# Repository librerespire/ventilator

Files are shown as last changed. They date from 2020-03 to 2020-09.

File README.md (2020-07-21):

ventilator

## Overview

An organized group of professionals from multiple disciplines focused on developing an  affordable, medical grade, robust,  open source  solution to acute shortage of mechanical ventilators due to COVID-19 pandemic. We have a core developer group collaborating online from different parts of the world, to design, build, test and validate the prototype.

- Even-though the initiation of the project was due to the COVID-19 outbreak, the LibreRespire team will continue the development of this ventilator to provide this essential medical device at a fraction of the cost of a commercial ventilator to developing countries, which are in dire shortage of ventilators regardless of the COVID-19.

## Objective

To design, build and validate a mechanical ventilator which meets minimum standards for long term ventilation with the aid of 3D printed parts and easily sourced components  which can be customized for local needs.

## Design Philosophy

The design will be publicly available for
- Study
- Modify
- Distribute
- Build
- Sell the design or hardware.

##  Collaborations

Current colloborations include, 

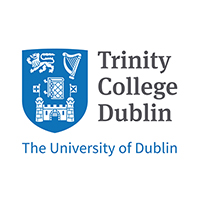
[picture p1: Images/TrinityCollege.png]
ventilator


Mechanical & Manufacturing Engineering, Trinity College, Dublin

If you wish to collaborate and contribute to the project, please contact us via team@librerespire.org. We will respond to every request depending on the requirements.  

## Sections

| Team | Directory |
|---|---|
| Design | [Design](/Design) |
| vBOX_MechanicalConcepts | [vBOX_MechanicalConcepts](/vBOX_MechanicalConcepts) |
| AirDelivery | [AirDelivery](/AirDelivery) |
| Electronics | [Electronics](/Electronics) |
| PowerSupply | [PowerSupply](/PowerSupply) |
| Housing | [Housing](/Housing) |

## Team
The core team consists of, 
- Manjula Herath (BDS,MD)
- Anuradha Rajapaksha (MBBS, MD,MRCS)
- Nushen Senevirathna (BSc Eng, MSc Eng) 
- Chamath Divarathne (Bsc Eng, MSc Eng, PhD)
- Roshana Mallawaarachchi (MBBS,MD)
- Nipuna Perera (Bsc)
- Chamila Dissanayake (Bsc Eng, MSc Eng)
- Rajive Wisidagama (BSc Eng, MSc Eng)
- Evaggelia Papia (PhD, DT),
- Prasad Ranaraja (Bsc Eng,Pg Dip, MBA)
- Sahan Wasala (ME (Aerospace), PhD) 
- Sameera Nanayakkara (BSc Eng, MSc Eng)

## Disclaimer

Currently LibreRespire ventilator is at experimental stage and not been validated  and approved for human or animal use clinically.

THE VENTILATOR INFORMATION IS PROVIDED “AS-IS, WHERE-IS,” WITHOUT REPRESENTATIONS, CONDITIONS, OR WARRANTIES OF ANY KIND, WHETHER EXPRESS OR IMPLIED, INCLUDING, BUT NOT LIMITED TO,  WARRANTIES OF MERCHANTABILITY OR FITNESS FOR A PARTICULAR PURPOSE, OR THAT THE USE OF THE VENTILATOR INFORMATION WILL NOT INFRINGE ANY PATENT, COPYRIGHT, TRADEMARK, OR OTHER PROPRIETARY RIGHTS.   THE RECIPIENT IS SOLELY RESPONSIBLE FOR DETERMINING THE APPROPRIATENESS OF USING, REPLICATING, OR REDISTRIBUTING THE LIBRERESPIRE VENTILATOR PROJECT INFORMATION AND DESIGN. IN THIS REGARD, THE RECIPIENT ASSUMES ALL LIABILITY FOR DAMAGES, OF WHATEVER NATURE AND DESCRIPTION, WHETHER IN CONTRACT OR IN TORT, WHICH MAY ARISE FROM THE USE OF THE VENTILATOR INFORMATION AND DESIGN.  THE LIBRERESPIRE TEAM, WILL NOT BE LIABLE TO THE RECIPIENT OR TO ANY THIRD PARTY FOR ANY LOSS, CLAIM, OR DEMAND MADE BY THE RECIPIENT, OR ANY LOSS, CLAIM, DEMAND, OR JUDGMENT AGAINST THE RECIPIENT BY ANY OTHER PARTY, DUE TO OR ARISING FROM THE USE OF THE VENTILATOR INFORMATION AND DESIGN BY THE RECIPIENT.

## Repository

Design documents can find [here](https://github.com/librerespire/ventilator)

## Team contacts

- Team email: [team@librerespire.org](mailto:team@librerespire.org)
- Slack channel: [librerespireorg.slack.com](https://librerespireorg.slack.com)

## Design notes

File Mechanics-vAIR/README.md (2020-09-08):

## Overview

This LibreRespire ventilator is organized in to two main components. This section
mainly focused on the vAIR.

- vBOX
  - The ventilator box which houses the main controllers and can functions
    independent of the gas delivery system, vAIR.

- vAIR
  - The ventilator air delivery system is responsible for the delivery of medical
    air and oxygen to the vBOX.

The main emphasis and development effort is focused on the vBOX. The goal is to
develop the vBOX to be couple with any standard gas delivery system such as wall
air, cylinders, compressors. bellows and pistons.

## Objective

However this section focuses on development of vAIR, the LibreRespire gas air delivery
system  which currently designed to work with the wall oxygen
and wall medical air. We
intend to build efficient, cost effective and easily sourced driving mechanism for
the vBOX.

## Team contacts

- Team email: [team@librerespire.org](mailto:team@librerespire.org)
- Slack channel: [librerespireorg.slack.com](https://librerespireorg.slack.com)

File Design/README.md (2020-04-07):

## The design

The design of the ventilator is based on the minimum standards published by the British government [here](https://www.gov.uk/government/publications/coronavirus-covid-19-ventilator-supply-specification/rapidly-manufactured-ventilator-system-specification)

## Objectives

- Design a ventilator composed of mechanical components freely available in most
regions of the world.
- Design a ventilator without the use of a Bellow or a “Bag”, which is either not
available or limited in number in an emergency situation.
- Minimize the use of mechanically moving components to increase durability.
- Easily sourced and easily assembled by a technician with limited medical
knowledge with off-the-shelf components.
- Option to use “Wall” oxygen / oxygen cylinders or a combination.
- Retain the capability to tolerate significant pressure difference or fluctuations.
- Be effective while retaining all the safety features.
- Maintain total cost of manufacture of the ventilator within affordable range,
especially to support developing countries.
- Use a programmable chip as a microcontroller which is a cheaper option yet be
powerful enough for real-time calculations.
- Use a visual aid (LCD) which is informative as well as user friendly.
- Ensuring a safe, reliable and robust design on par with industry standards.

## Functional specification

- Functional Modes
a. Pressure control Continuous Mandatory Ventilation (PC- CMV)
b. Pressure control Intermittent Mandatory Ventilation (PC-IMV)
c. Continuous Positive Air Pressure (CPAP)

- Gas supply
a. Air and O2 supplied separately
b. Option to use wall connectors (4Bar) or Cylinder(Variable Pressure) - System can
compensate for pressure drop/variation

- Visual controls and digital features
a. Feedback control of pressure and flow.
b. Ventilator output for TV, RR, PEEP, PIP, MV, Spontaneous ventilation rate
c. Alarms
d. iOS and Android controller app with a dashboard to display patient data for
remote monitoring
e. Data analytic as an added feature for pattern recognition etc. for assisting
doctors

## Hardware specification

| Parameter | Range | Accuracy | Adjustments |
|---|---|---|---|
| Tidal volume (TV) | 250-1000 ml |  25 ml |  10 ml |
| Respiratory rate (RR)) | 10 – 30 bpm | 0.5 bpm | 1 bpm |
| I:E ratio | 1:3 - 2:1 | |  0.1 |
| Oxygen saturation | FiO2 0.21 - 1.0 | 0.05 |  |
| FiO<sub>2</sub> | 0.21 - 1.0 |  5% |  10% |
| Peak inspiratory pressure | 40 mmHg |  1 mmHg |  1 mmHg |
| Safety valve | 40 - 60 mmHg |  Absolute |  +5 mmHg |
| Inspiratory pause | 25% | |  1% |

## Main control unit

- Processing
  - 32 bit ARM
- Display
  - LCD, 5", capacitive touchscreen (option to use a low cost 3” to high end10” designs)
- Alarms
  - Low RR
  - Low TV
  - PIP
  - Circuit leaks/disconnections
  - Circuit obstruction

## Sensors

- Pressure sensors
- Oxygen sensor
- Flow sensor

## Valve Specifications

- Actuated pneumatic solenoid valve NC
- Needle valve
- Solenoid Valve NO
- Safety valves
- One way rubber diaphragm valves
- PEEP Valve

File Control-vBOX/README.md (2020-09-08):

## Overview

The LibreRespire ventilator is organized in to two main components. This section
mainly focused on the vBOX, the heart of the LibreRespire system.

- vBOX
  - The ventilator box which houses the main controllers and sensors and can functions independent of the gas delivery system, vAIR.

- vAIR
  - The ventilator air delivery system is responsible for the delivery of medical
    air and oxygen to the vBOX.

The main emphasis and development effort is focused on the vBOX. The goal is to
develop the vBOX to be couple with any standard gas delivery system such as wall
air, cylinders, compressors. bellows and pistons.

## Objective

The main driving concept behind the LibreRespire development is its modular design
which can be tailored to the individual needs and can easily experimented, debugged
and improved.

## Design

The vBOX is divided in to 6 modules.
- iMixingUnit
  - Responsible for medical air and oxygen mixing to maintain a given FiO<sub>2</sub>.
    Currently  FiO<sub>2</sub> needs to be set manually.
    - Issue tracker.
       * [ ]  Automate  FiO<sub>2</sub> setting.
       * [ ]  Select appropriate oxygen sensor.
       * [ ]  Integrate oxygen sensor.
       * [ ]  Improve physical design.   

- iVenturiUnit
  - Responsible for sensing the pressure difference and flow rates in the control
  loop during inspiration. Operates on bernoulli's principle and allows the flow
  rate to be calculated independent of a separate flow sensor.
  - Issue tracker.
     * [ ]  Selection of a single differential pressure sensor.
     * [ ]  Improve physical design.

- iControlUnit
  - The main inspiratory output. Houses the emergency valve and the one way valve.  
  - Issue tracker.
     * [ ]  Select appropriate rupture disk to act as the emergency valve.
     * [ ]  Decide on the cost effectiveness of a separate flow sensor.
     * [ ]  Optimize one way valve.
     * [ ]  Standardize output port.

- eControlUnit
  - The main port of entry of the expiratory limb. Houses one way valve and the
  main flow sensor.
  Issue tracker.
    * [ ]  Select appropriate flow sensor.

- eVenturiUnit
  - Act to control the expiratory flow and calculate the pressure difference and the
  expiratory flow rates.
  - Issue tracker.
     * [ ]  Selection of a single differential pressure sensor.

- ePEEPControl
  - Currently controlled by the off the shelf manual PEEP valve.
  - Issue tracker.
     * [ ]  Development of a electronically controlled PEEP valve.
     * [ ]  Validation of the electronically controlled PEEP valve.

## Team contacts

- Team email: [team@librerespire.org](mailto:team@librerespire.org)
- Slack channel: [librerespireorg.slack.com](https://librerespireorg.slack.com)

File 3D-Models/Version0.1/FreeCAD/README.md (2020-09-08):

This folder contains CAD drawings in FreeCAD format

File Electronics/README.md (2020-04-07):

ventilator

# LibreRespire Electronic module
---

This functions as the brain of the LibreRespire, and tailors the output to the
user specified settings based on sensory input.   

## Repository

Design documents can find [here](https://github.com/librerespire/ventilator)

## Team contacts

- Team email: [team@librerespire.org](mailto:team@librerespire.org)
- Slack channel: [librerespireorg.slack.com](https://librerespireorg.slack.com)

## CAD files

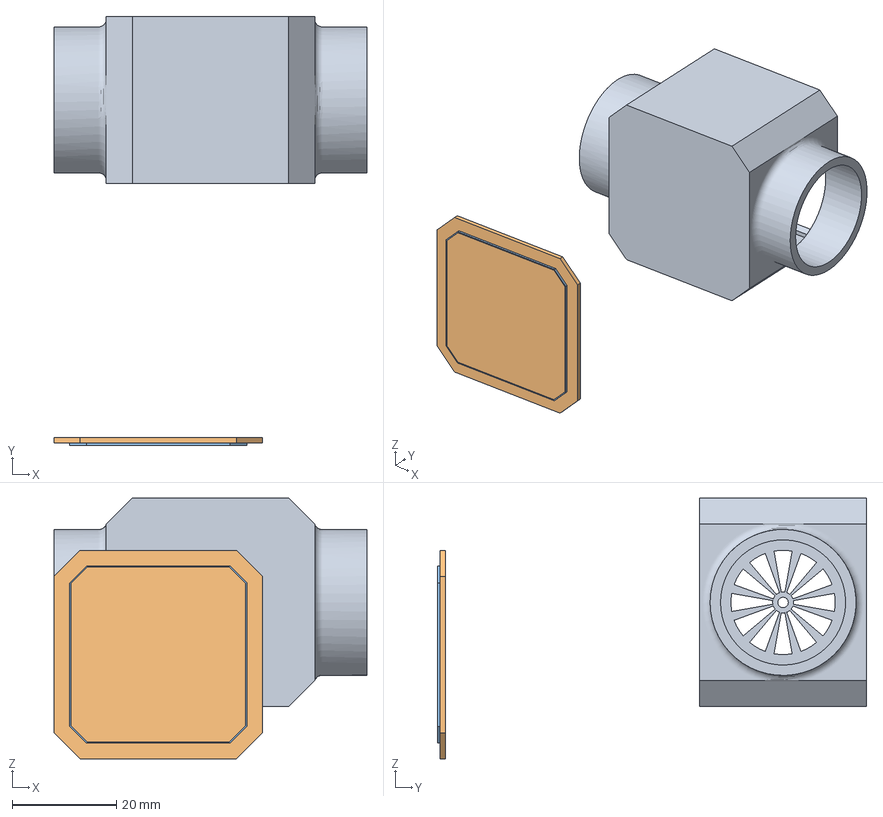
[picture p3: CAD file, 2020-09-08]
3D-Models/Version0.1/FreeCAD/ExpirationChamber.FCStd
60.0 x 82.3 x 50.0 mm
ExpirationChamber-CAP

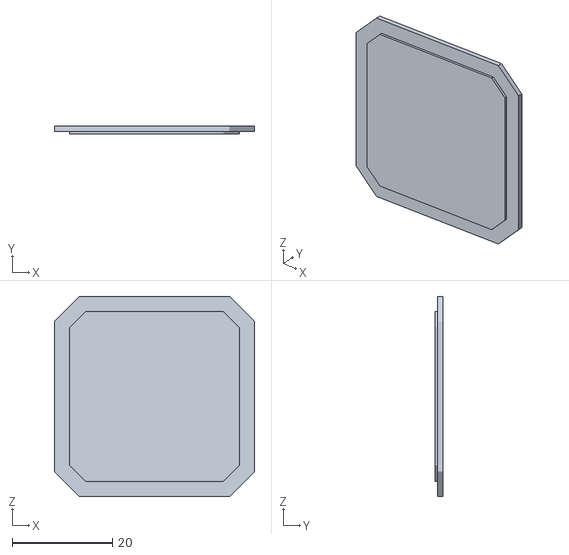
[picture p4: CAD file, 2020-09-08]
3D-Models/Version0.1/InspiControlChamberCap.STL
40.0 x 1.50 x 40.0

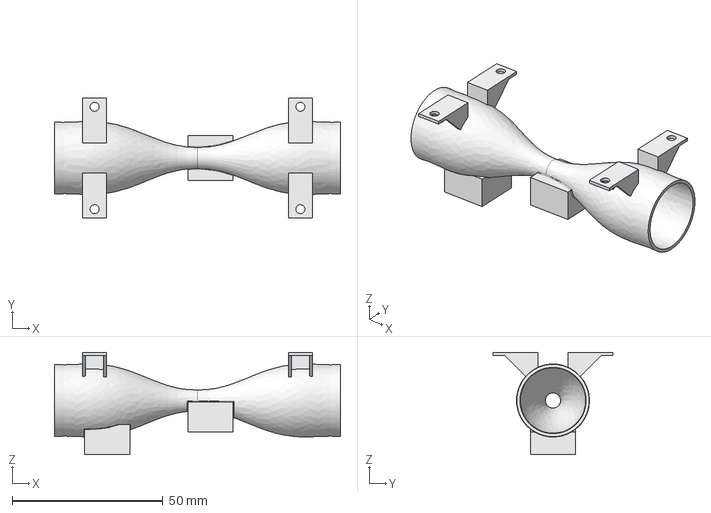
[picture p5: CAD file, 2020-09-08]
3D-Models/Version0.1/FreeCAD/VentureTube.FCStd
95.0 x 40.0 x 34.0 mm

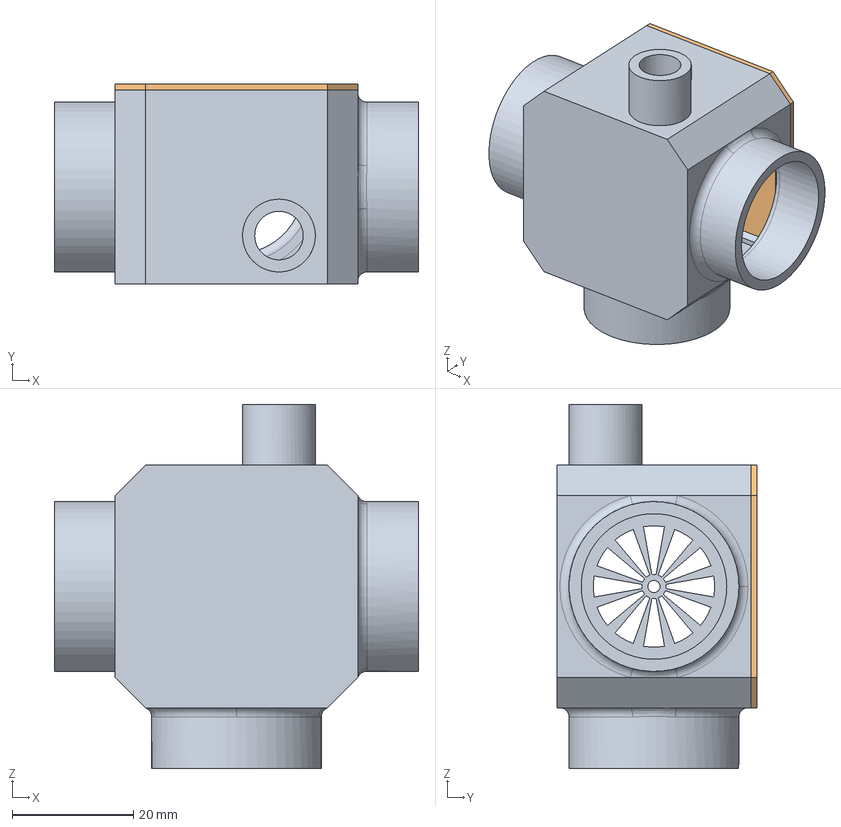
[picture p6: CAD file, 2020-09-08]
3D-Models/Version0.1/FreeCAD/InspiControlChamber.FCStd
60.0 x 33.0 x 60.0 mm

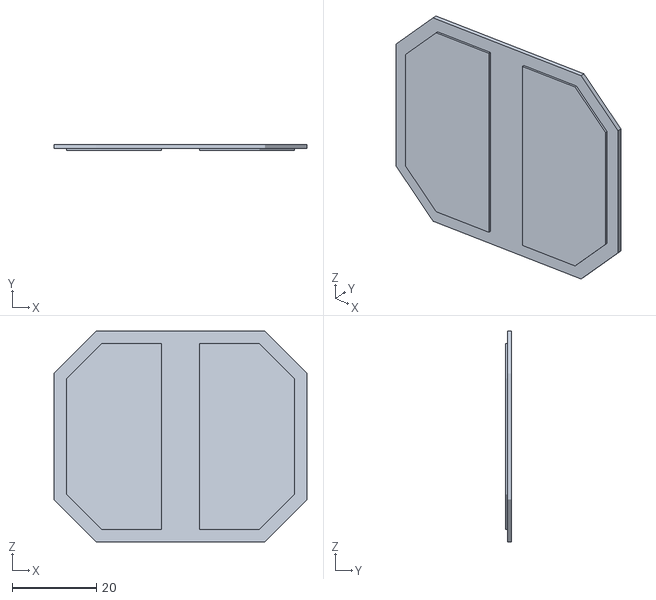
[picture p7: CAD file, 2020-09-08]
3D-Models/Version0.1/MixingChamberCap.STL
60.0 x 1.50 x 50.0

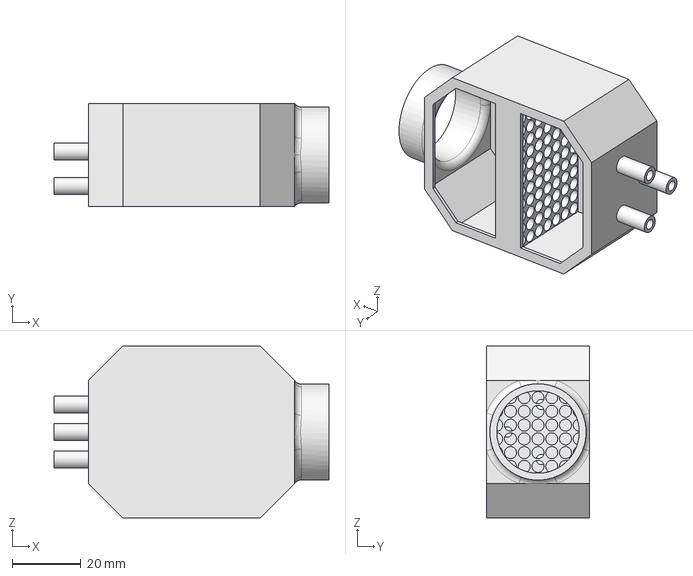
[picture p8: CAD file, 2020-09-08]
3D-Models/Version0.1/FreeCAD/MixingChamber.FCStd
80.0 x 30.0 x 50.0 mm

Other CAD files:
3D-Models/Version0.1/ExpirationChamber-CAP.stl
3D-Models/Version0.1/VenturiTube.STL
3D-Models/Version0.1/ExpirationChamber.stl
3D-Models/Version0.1/InspiControlChamber.STL
3D-Models/Version0.1/MixingChamber.STL

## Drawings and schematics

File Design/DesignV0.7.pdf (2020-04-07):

## Air Delivery Unit

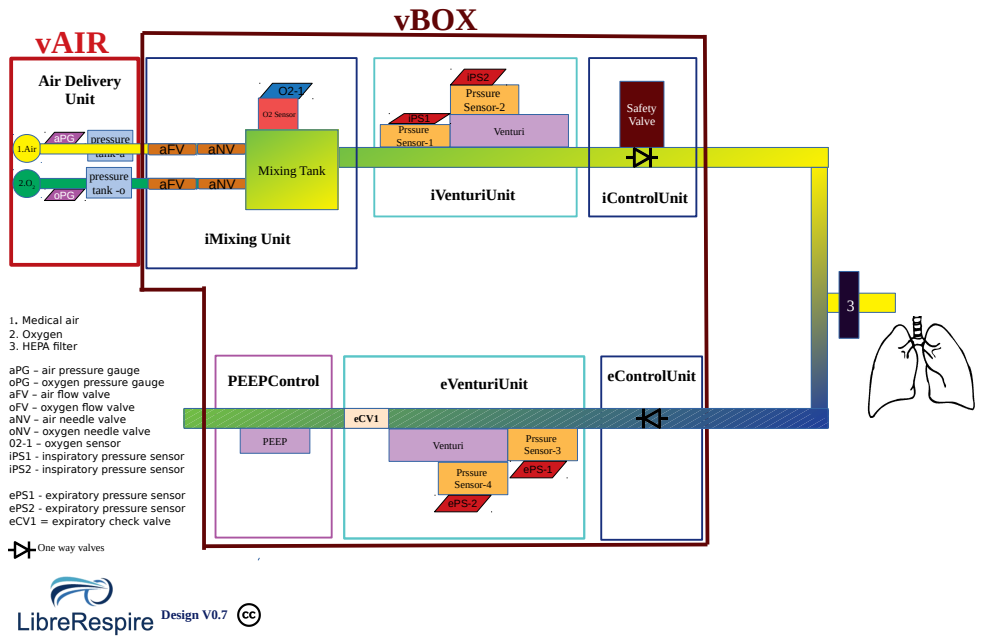
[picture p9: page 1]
1. Medical air 2. Oxygen 3. HEPA filter; Design V0.7; pressure tank-a ¹.Air; aPG; iControlUnit; Safety Valve; oPG; iVenturiUnit; Venturi; Prssure Sensor-2; iPS2; Prssure Sensor-1; iPS1; aNV; pressure; tank -o; aFV; Prssure; ePS-1; Sensor-4; ePS-2; iMixing Unit; vBOX; eVenturiUnit; eControlUnit; O2 Sensor; PEEPControl; Mixing Tank; vAIR

aPG – air pressure gauge
oPG – oxygen pressure gauge
aFV – air flow valve
oFV – oxygen flow valve
aNV – air needle valve
oNV – oxygen needle valve
02-1 – oxygen sensor
iPS1 - inspiratory pressure sensor
iPS2 - inspiratory pressure sensor

eCV1

PEEP | | Venturi | Prssure Sensor-3

ePS1 - expiratory pressure sensor
ePS2 - expiratory pressure sensor
eCV1 = expiratory check valve

One way valves

Design V0.7

## Power Supply

## Plugged in

## Rechargeable/Hot swappable

## MCU

## User Interface

I:E Ratio

2:1 – 1:2

Respiratory Rate
5-40 bpm

Expiratory pressure I:E Ratio 0 - 20 cmH20

## FiO2

20% -100% | Active Buzzer Alarm Inspiratory pressure
40 cmH20

Minute Ventilation (low/High) alarm Peak pressure, Low expiratory pressure Disconnection alarm
Low expiratory pressure
Oxygen concentration
Non-rebreathing valves

## Pressure Support

5-15

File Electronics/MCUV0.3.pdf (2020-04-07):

uIP | uRR | uPEEP | uPS | uTV
Pressure | Flow | O2

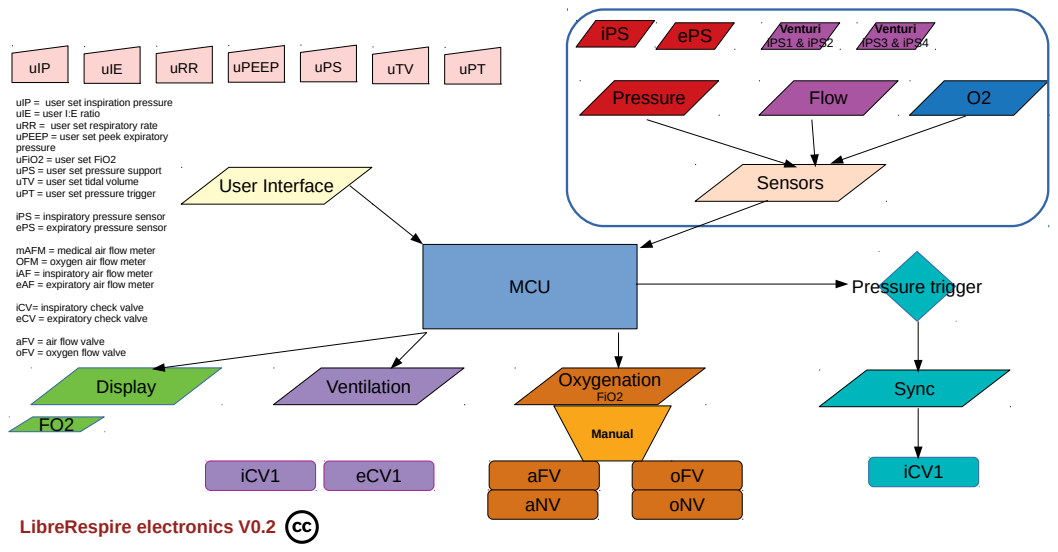
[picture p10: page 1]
MCU; Sensors; Display; Ventilation; Oxygenation; FiO2; Sync; User Interface; iPS; ePS; Venturi; iPS1 & iPS2; Venturi iPS3 & iPS4; iCV1; eCV1; aFV; oFV; Pressure trigger; LibreRespire electronics V0.2; uIE; uPT; aNV; oNV; Manual FO2

uIP = user set inspiration pressure
uIE = user I:E ratio
uRR = user set respiratory rate
uPEEP = user set peek expiratory
pressure
uFiO2 = user set FiO2
uPS = user set pressure support
uTV = user set tidal volume
uPT = user set pressure trigger

iPS = inspiratory pressure sensor
ePS = expiratory pressure sensor

mAFM = medical air flow meter
OFM = oxygen air flow meter
iAF = inspiratory air flow meter
eAF = expiratory air flow meter

iCV= inspiratory check valve
eCV = expiratory check valve

aFV = air flow valve
oFV = oxygen flow valve

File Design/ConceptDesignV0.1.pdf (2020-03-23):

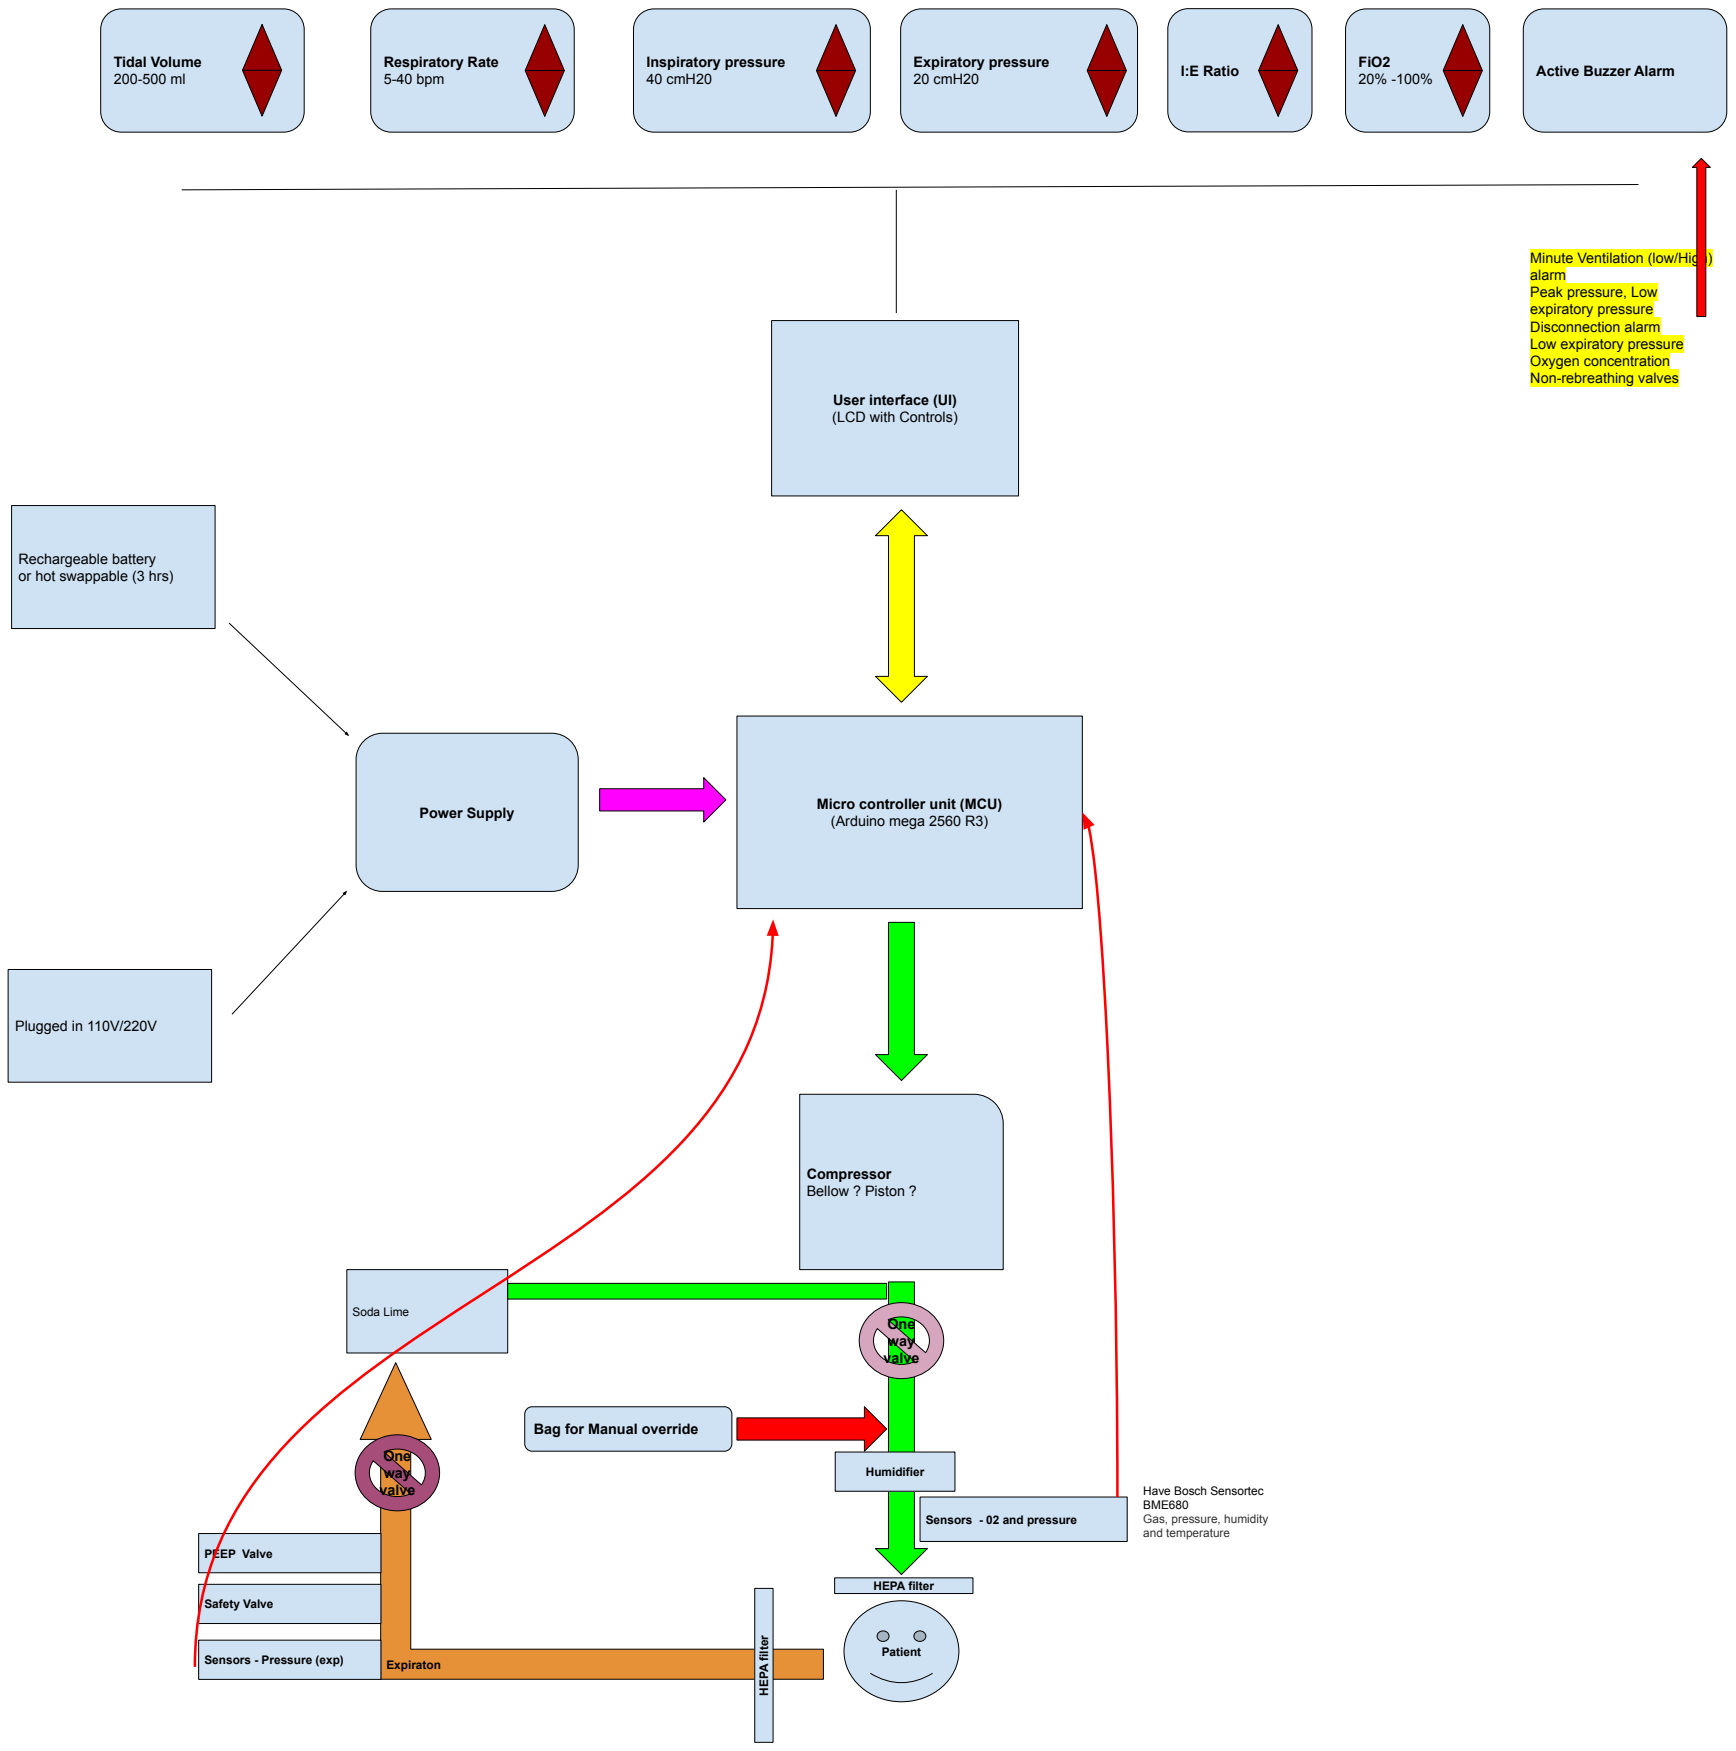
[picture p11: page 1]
Power Supply; Plugged in 110V/220V; Tidal Volume 200-500 ml; Respiratory Rate 5-40 bpm; Inspiratory pressure 40 cmH20; Expiratory pressure 20 cmH20; I:E Ratio; Active Buzzer Alarm; FiO2 20% -100%; Compressor Bellow ? Piston ?; One way valve; Humidifier; Patient; Soda Lime; Expiraton; Safety Valve; HEPA filter; PEEP Valve

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

User interface (UI)
(LCD with Controls)

Rechargeable battery
or hot swappable (3 hrs)

Micro controller unit (MCU)
(Arduino mega 2560 R3)

Bag for Manual override

Have Bosch Sensortec
BME680
Gas, pressure, humidity
and temperature

Sensors - 02 and pressure

Sensors - Pressure (exp)

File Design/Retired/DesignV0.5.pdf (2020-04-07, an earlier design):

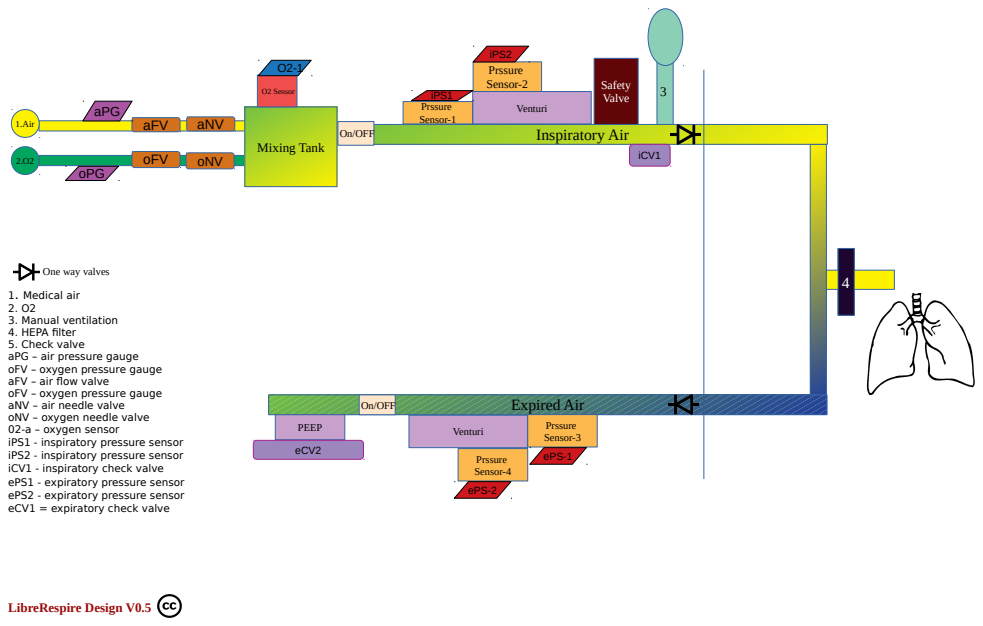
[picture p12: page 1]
Inspiratory Air; LibreRespire Design V0.5; Safety Valve; Mixing Tank; iCV1; eCV2; aFV; oFV; O2 Sensor; aPG; oPG; oNV; aNV; Prssure; ePS-1; Sensor-4; ePS-2; Venturi; Prssure Sensor-2; iPS2; Prssure Sensor-1; iPS1; 1.Air; On/OFF

One way valves
1. Medical air
3. Manual ventilation
4. HEPA filter
5. Check valve
aPG – air pressure gauge
oFV – oxygen pressure gauge
aFV – air flow valve
aNV – air needle valve
oNV – oxygen needle valve
02-a – oxygen sensor
iPS1 - inspiratory pressure sensor
iPS2 - inspiratory pressure sensor
iCV1 - inspiratory check valve
ePS1 - expiratory pressure sensor
ePS2 - expiratory pressure sensor
eCV1 = expiratory check valve

On/OFF | Expired Air

PEEP | | Venturi | Prssure Sensor-3

LibreRespire Design V0.5

## Power Supply

## Plugged in

## Recharhable/Hot swappable

## MCU

(Arduino mega 2560 R3)

## User Interface

I:E Ratio

2:1 – 1:2

Respiratory Rate
5-40 bpm

Expiratory pressure I:E Ratio 0 - 20 cmH20

## FiO2

20% -100% | Active Buzzer Alarm Inspiratory pressure
40 cmH20

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

## Pressure Support

5-15

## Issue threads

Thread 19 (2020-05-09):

Mechanical vs electronic PEEP

cmfsx, 2020-05-09:
P3 PEEP is not relevant if the PEEP valve is mechanical. P3 PEEP should be included in the loop when electronically controlled PEEP valve is used.

https://github.com/librerespire/ventilator/blob/519f6ead6bdfed8257125dfd74dad3634d3425b2/Firmware/RaspberryPi/backend-pi/Controller.py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

chamrepo, 2020-05-17:
Controlling pressure was made out of scope for this mode

Closed 2020-05-17.

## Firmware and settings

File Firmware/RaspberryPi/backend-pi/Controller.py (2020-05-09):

# Controller v1.1
# 2020-05-09 12.05 AM (Melb)

import math
import time
from datetime import datetime
import threading
import RPi.GPIO as GPIO
from SensorReader import SensorReader
import logging.config

# Parameters
Ti = 5          # inspiratory time
Te = 5          # expiratory time
Tw = 1          # waiting time
Vt = 5          # tidal volume
Pi = 2000       # peak inspiratory pressure in cmH2O
Peep = 900      # PEEP
PWM_FREQ = 4    # frequency for PWM

# Constants
SI_PIN = 12     # PIN (PWM) for inspiratory solenoid
SE_PIN = 13     # PIN (PWM) for expiratory solenoid
DUTY_RATIO_100 = 100
DUTY_RATIO_0 = 0
NUMBER_OF_SENSORS = 4
BUS_1 = 1
BUS_2 = 3
BUS_3 = 4
BUS_4 = 5

pressure_data = [0] * 6

# Initialize digital output pins
GPIO.setmode(GPIO.BCM)
GPIO.setwarnings(False)

GPIO.setup(SI_PIN, GPIO.OUT)
GPIO.setup(SE_PIN, GPIO.OUT)

pwm_i = GPIO.PWM(SI_PIN, PWM_FREQ)
pwm_e = GPIO.PWM(SE_PIN, PWM_FREQ)

# declare logger parameters
logging.config.fileConfig(fname='logger.conf', disable_existing_loggers=False)
logger = logging.getLogger(__name__)


def thread_slice(pressure_data, index):
    sr = SensorReader(index)
    pressure = sr.read_pressure()
    pressure_data[index] = pressure


def read_data():
    # read four pressure sensors from the smbus and return actual values
    threads = list()
    for index in [BUS_1, BUS_2, BUS_3, BUS_4]:
        thread = threading.Thread(target=thread_slice, args=(pressure_data, index,))
        threads.append(thread)
        thread.start()

    for index, thread in enumerate(threads):
        thread.join()
    logger.debug("Pressure: P1[%.2f], P2[%.2f], P3[%.2f], P4[%.2f]" %
                 (pressure_data[BUS_1], pressure_data[BUS_2], pressure_data[BUS_3], pressure_data[BUS_4]))
    return pressure_data[BUS_1], pressure_data[BUS_2], pressure_data[BUS_3], pressure_data[BUS_4]


def calculate_k(p1, p2, flow_rate):
    return flow_rate / math.sqrt(abs(p1 - p2))


# With current settings flow meter will be calibrated over 5 seconds (nSamples * delay)
def calibrate_flow_meter(flow_rate):
    """ returns the calibrated k for both insp and exp flow meters, calculated based on multiple pressure readings """

    # Turn ON both the solenoids fully for calibration
    pwm_i.start(100)
    pwm_e.start(100)

    nSamples = 10  # average over 10 samples
    delay = 0.5  # 0.5 seconds
    n = 0
    ki = 0
    ke = 0
    # Take the average over 'nSamples' pressure readings, 'delay' seconds apart to calculate k
    while n < nSamples:
        p1, p2, p3, p4 = read_data()
        ki += calculate_k(p1, p2, flow_rate)
        ke += calculate_k(p3, p4, flow_rate)
        n += 1
        time.sleep(delay)

    ki /= nSamples
    ke /= nSamples
    logger.debug("Flow meter was calibrated. k_ins = %.4f, k_exp = %.4f" % (ki, ke))
    return ki, ke


def control_solenoid(pin, duty_ratio):
    if pin == SI_PIN:
        pwm_i.ChangeDutyCycle(duty_ratio)
    elif pin == SE_PIN:
        pwm_e.ChangeDutyCycle(duty_ratio)

    logger.debug("Changed duty cycle to " + str(duty_ratio) + "on pin " + str(pin))

# def control_solenoid(pin, duty_ratio):
#     # read four pressure sensors from the smbus and return actual values
#     logger.info("Entering control_solenoid()...")
#     on_time = PWM_PERIOD * duty_ratio
#     off_time = PWM_PERIOD * (1 - duty_ratio)
#
#     if pin in threads_map:
#         threads_map[pin].stop()
#         threads_map[pin].join()
#
#     t = PWMController(datetime.now().strftime('%Y%m%d%H%M%S%f'), pin, on_time, off_time)
#     threads_map[pin] = t
#
#     # Don't want these threads to run when the main program is terminated
#     t.daemon = True
#     t.start()
#
#     logger.info("Leaving control_solenoid().")


def get_average_volume_rate(is_insp_phase):
    """ read p1 and p2 over 200 milliseconds and return average volume rate """

    nSamples = 4  # average over 4 samples
    delay = 0.05  # 50 milliseconds
    n = 0
    q = 0
    # Take the average over 'nSamples' pressure readings, 'delay' seconds apart to calculate flow rate
    while n < nSamples:
        p1, p2, p3, p4 = read_data()
        if is_insp_phase:
            q += Ki * math.sqrt(abs(p1 - p2))
        else:
            q += Ke * math.sqrt(abs(p3 - p4))

        n += 1
        time.sleep(delay)

    return q / nSamples


def calculate_pid_duty_ratio(demo_level):
    """ TODO: implement the PID controller to determine the required duty ratio to achieve the desired pressure curve
        Currently a temporary hack is implemented with demo_level """
    duty_ratio = 100
    if demo_level == 1:
        duty_ratio = 20

    return duty_ratio


def insp_phase(demo_level):
    """ inspiratory phase tasks
        demo_level is a temporary hack to introduce two flow rate levels until pid controller is implemented """

    logger.info("Entering inspiratory phase...")
    start_time = datetime.now()
    t1, t2 = start_time, start_time
    ti = 0
    q1, q2 = 0, 0
    vi = 0

    # Control solenoids
    control_solenoid(SE_PIN, DUTY_RATIO_0)

    while ti < Ti and vi < Vt:
        t1 = t2
        q1 = q2
        q2 = get_average_volume_rate(True)
        t2 = datetime.now()

        vi += (q1 + q2) / 2 * (t2 - t1).total_seconds() / 60

        di = calculate_pid_duty_ratio(demo_level)
        control_solenoid(SI_PIN, di)

        ti = (datetime.now() - start_time).total_seconds()
        logger.info("Flow rate: %.2f L/min, Volume: %.2f L,  Time: %.1f sec" % (q2, vi, ti))

    logger.info("Leaving inspiratory phase.")


def exp_phase():
    """ expiratory phase tasks """
    logger.info("Entering expiratory phase...")
    start_time = datetime.now()
    t1, t2 = start_time, start_time
    ti = 0
    q1, q2 = 0, 0
    vi = 0
    p3 = Peep

    control_solenoid(SI_PIN, DUTY_RATIO_0)
    control_solenoid(SE_PIN, DUTY_RATIO_100)

    while ti < Te and p3 >= Peep:
        t1 = t2
        q1 = q2
        q2 = get_average_volume_rate(False)
        t2 = datetime.now()

        vi += (q1 + q2) / 2 * (t2 - t1).total_seconds() / 60

        p1, p2, p3, p4 = read_data()
        if p3 < Peep:
            control_solenoid(SE_PIN, 0)

        ti = (datetime.now() - start_time).total_seconds()
        logger.info("Flow rate: %.2f L/min, Volume: %.2f L, Pressure_insp: %.2f cmH20, Time: %.1f sec"
                    % (q2, vi, convert_pressure(p3), ti))

    logger.info("Leaving expiratory phase.")
    logger.info("Actual tidal volume delivered : %.3f L " % vi)


def wait_phase():
    """ waiting phase tasks """
    logger.info("Entering wait phase...")
    control_solenoid(SI_PIN, DUTY_RATIO_0)
    control_solenoid(SE_PIN, DUTY_RATIO_0)
    time.sleep(Tw)
    logger.info("Leaving wait phase.")


def convert_pressure(p_hpa):
    """ returns inspiratory pressure in cmH2O"""
    return p_hpa * 1.0197442


#######################################################################################################
# 12 here is the intended flow_rate for calibration in L/min
Ki, Ke = calibrate_flow_meter(12)

while True:
    # slow flow rate
    # logger.info("***** Slower flow rate cycle *****")
    # insp_phase(1)
    # exp_phase()
    # wait_phase()
    # logger.info("***** Slower cycle end *****")

    # faster flow rate
    logger.info("***** Faster flow rate cycle *****")
    insp_phase(2)
    exp_phase()
    wait_phase()
    logger.info("***** Faster cycle end *****")

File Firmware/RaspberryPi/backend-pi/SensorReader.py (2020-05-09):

import smbus
import time
from datetime import datetime


class SensorReader:
    bus = None
    delay = 0.05
    pressure = -0
    cTemp = 999
    fTemp = 999
    bus_number = 0

    def __init__(self, bus_number):
        # Get I2C
        self.bus_number = bus_number
        self.bus = smbus.SMBus(self.bus_number)

    def read_temp(self):
        #Reading Data from i2c bus 3
        b1 = self.bus.read_i2c_block_data(0x76, 0x88, 24)
        # Convert the data
        # Temp coefficents
        dig_T1 = b1[1] * 256 + b1[0]
        dig_T2 = b1[3] * 256 + b1[2]
        if dig_T2 > 32767 :
            dig_T2 -= 65536
        dig_T3 = b1[5] * 256 + b1[4]
        if dig_T3 > 32767 :
            dig_T3 -= 65536
        # BMP280 address, 0x76(118)
        # Select Control measurement register, 0xF4(244)
        #		0x27(39)	Pressure and Temperature Oversampling rate = 1
        #					Normal mode
        self.bus.write_byte_data(0x76, 0xF4, 0x27)
        # BMP280 address, 0x76(118)
        # Select Configuration register, 0xF5(245)
        #		0xA0(00)	Stand_by time = 1000 ms
        self.bus.write_byte_data(0x76, 0xF5, 0xA0)
        time.sleep(self.delay)
        # BMP280 address, 0x76(118)
        # Read data back from 0xF7(247), 8 bytes
        # Pressure MSB, Pressure LSB, Pressure xLSB, Temperature MSB, Temperature LSB
        # Temperature xLSB, Humidity MSB, Humidity LSB
        data = self.bus.read_i2c_block_data(0x76, 0xF7, 8)
        # Convert temperature data to 19-bits
        adc_t = ((data[3] * 65536) + (data[4] * 256) + (data[5] & 0xF0)) / 16
        # Temperature offset calculations
        var1 = ((adc_t) / 16384.0 - (dig_T1) / 1024.0) * (dig_T2)
        var2 = (((adc_t) / 131072.0 - (dig_T1) / 8192.0) * ((adc_t)/131072.0 - (dig_T1)/8192.0)) * (dig_T3)
        t_fine = (var1 + var2)
        self.cTemp = (var1 + var2) / 5120.0
        self.fTemp = self.cTemp * 1.8 + 32

    def read_pressure(self):
        #Reading Data from i2c bus 3
        b1 = self.bus.read_i2c_block_data(0x76, 0x88, 24)
        # Convert the data
        # Temp coefficents
        dig_T1 = b1[1] * 256 + b1[0]
        dig_T2 = b1[3] * 256 + b1[2]
        if dig_T2 > 32767 :
            dig_T2 -= 65536
        dig_T3 = b1[5] * 256 + b1[4]
        if dig_T3 > 32767 :
            dig_T3 -= 65536
        # Pressure coefficents
        dig_P1 = b1[7] * 256 + b1[6]
        dig_P2 = b1[9] * 256 + b1[8]
        if dig_P2 > 32767 :
            dig_P2 -= 65536
        dig_P3 = b1[11] * 256 + b1[10]
        if dig_P3 > 32767 :
            dig_P3 -= 65536
        dig_P4 = b1[13] * 256 + b1[12]
        if dig_P4 > 32767 :
            dig_P4 -= 65536
        dig_P5 = b1[15] * 256 + b1[14]
        if dig_P5 > 32767 :
            dig_P5 -= 65536
        dig_P6 = b1[17] * 256 + b1[16]
        if dig_P6 > 32767 :
            dig_P6 -= 65536
        dig_P7 = b1[19] * 256 + b1[18]
        if dig_P7 > 32767 :
            dig_P7 -= 65536
        dig_P8 = b1[21] * 256 + b1[20]
        if dig_P8 > 32767 :
            dig_P8 -= 65536
        dig_P9 = b1[23] * 256 + b1[22]
        if dig_P9 > 32767 :
            dig_P9 -= 65536
        # BMP280 address, 0x76(118)
        # Select Control measurement register, 0xF4(244)
        #		0x27(39)	Pressure and Temperature Oversampling rate = 1
        #					Normal mode
        self.bus.write_byte_data(0x76, 0xF4, 0x27)
        # BMP280 address, 0x76(118)
        # Select Configuration register, 0xF5(245)
        #		0xA0(00)	Stand_by time = 1000 ms
        self.bus.write_byte_data(0x76, 0xF5, 0xA0)
        time.sleep(self.delay)
        # BMP280 address, 0x76(118)
        # Read data back from 0xF7(247), 8 bytes
        # Pressure MSB, Pressure LSB, Pressure xLSB, Temperature MSB, Temperature LSB
        # Temperature xLSB, Humidity MSB, Humidity LSB
        data = self.bus.read_i2c_block_data(0x76, 0xF7, 8)
        # Convert pressure data to 19-bits
        adc_p = ((data[0] * 65536) + (data[1] * 256) + (data[2] & 0xF0)) / 16
        adc_t = ((data[3] * 65536) + (data[4] * 256) + (data[5] & 0xF0)) / 16
        # Temperature offset calculations
        var1 = ((adc_t) / 16384.0 - (dig_T1) / 1024.0) * (dig_T2)
        var2 = (((adc_t) / 131072.0 - (dig_T1) / 8192.0) * ((adc_t)/131072.0 - (dig_T1)/8192.0)) * (dig_T3)
        t_fine = (var1 + var2)
        # Pressure offset calculations
        var1 = (t_fine / 2.0) - 64000.0
        var2 = var1 * var1 * (dig_P6) / 32768.0
        var2 = var2 + var1 * (dig_P5) * 2.0
        var2 = (var2 / 4.0) + ((dig_P4) * 65536.0)
        var1 = ((dig_P3) * var1 * var1 / 524288.0 + ( dig_P2) * var1) / 524288.0
        var1 = (1.0 + var1 / 32768.0) * (dig_P1)
        p = 1048576.0 - adc_p
        p = (p - (var2 / 4096.0)) * 6250.0 / var1
        var1 = (dig_P9) * p * p / 2147483648.0
        var2 = p * (dig_P8) / 32768.0
        self.pressure = (p + (var1 + var2 + (dig_P7)) / 16.0) / 100
        return self.pressure
        # Output data to screen ** uncomment this part to see values form sensors
        # print("""\t======== bus %d ==========
        # Temperature in Celsius : %.2f C
        # Temperature in Fahrenheit : %.2f F
        # Pressure : %.2f hPa
        # Time: %s
        # =======================\n""" % (self.bus_number, self.cTemp,
        #             self.fTemp,
        #             self.pressure,
        #             datetime.now().strftime("%Y-%m-%d %H:%M:%S.%f")))

    def get_pressure(self):
        self.read_pressure()
        return self.pressure

    def get_ftemp(self):
        self.read_temp(self)
        return self.fTemp

    def get_ctemp(self):
        self.read_temp(self)
        return self.cTemp

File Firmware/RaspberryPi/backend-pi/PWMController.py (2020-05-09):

import threading
import time
import RPi.GPIO as GPIO
import logging
import logging.config

# declare logger parameters
logger = logging.getLogger(__name__)


class PWMController(threading.Thread):
    """ Thread class with a stop() method.
        Handy class to implement PWM on digital output pins """

    def __init__(self, thread_id, pin, on_time, off_time):
        threading.Thread.__init__(self)
        self.__thread_id = thread_id
        self.__pin = pin
        self.__on_time = on_time
        self.__off_time = off_time
        self.__stop_event = threading.Event()

        # TODO: Setting up the pins should be moved to the main script 'Controller.py'
        # GPIO.setmode(GPIO.BCM)
        # GPIO.setwarnings(False)
        # GPIO.setup(pin, GPIO.OUT)

    def stop(self):
        self.__stop_event.set()
        # print(str(self.__thread_id) + ": set the stop event")

    def stopped(self):
        return self.__stop_event.is_set()

    def run(self):
        while True:
            if self.stopped():
                # print(str(self.__thread_id) + ": thread has stopped. exiting")
                break;
            logger.debug(str(self.__pin) + ": ON--" + str(self.__on_time))
            if self.__on_time > 0.02:
                GPIO.output(self.__pin, GPIO.HIGH)
                logger.debug("On wait time: %.3f" % self.__on_time)
                time.sleep(self.__on_time)
            logger.debug(str(self.__pin) + ": OFF--" + str(self.__off_time))
            if self.__off_time > 0.02:
                GPIO.output(self.__pin, GPIO.LOW)
                logger.debug("Off wait time: %.3f" % self.__off_time)
                time.sleep(self.__off_time)

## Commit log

2020-05-07 PressureSensor busnumber changed
2020-05-07 floting type print change
2020-05-07 rename sensorreader class file
2020-05-07 introduce threading to SensorReader
2020-05-07 print function changed
2020-05-07 print function fixed
2020-05-07 print fucntion fixed
2020-05-07 miliseconds added to print function
2020-05-07 temperature removed from main function and added to different function
2020-05-07 SensorReader imported to Controller
2020-05-07 pressure_data set to 5
2020-05-07 pressure_data to print
2020-05-07 pressure_data fixed size to 5
    [Controller.py]
2020-05-07 pressure_data fixed size to 6
    [Controller.py]
2020-05-07 pressure_data[] array fixed size
    [Controller.py]
2020-05-08 Added PWM capability on a digital port using multi threading
2020-05-08 Added thread_id based on timestamp
2020-05-08 Added thread_id based on timestamp for main controller
2020-05-08 Configured digital output pins for altered PWM controlling
2020-05-08 Increase the PWM_PERIOD for testing using LED
2020-05-08 Fine tuning parameter for testing with LED
2020-05-08 Moved GPIO pin configuration to Controller.py
2020-05-08 Fine tuning parameters for testing with LED
2020-05-08 Add extra logs to PWMController.py
2020-05-08 Flow rate identifier added to logs
2020-05-09 Added raspberry pi's pwm channels
2020-05-09 Increased pwm period
2020-05-09 Used hardware PWM available in RaspberryPi
2020-07-24 3D models
    [control chamber cap.STL, control chamber.STL, mixing chamber cap.STL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]
2020-09-03 Create STL
2020-09-08 FreeCAD drawings
    [ExpirationChamber.FCStd, InspiControlChamber.FCStd, MixingChamber.FCStd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]
2020-12-13 Bump ini from 1.3.5 to 1.3.8 in /Firmware/RaspberryPi/frontend-pi
    Bumps [ini](https://github.com/isaacs/ini) from 1.3.5 to 1.3.8.
    - [Release notes](https://github.com/isaacs/ini/releases)
    - [Commits](https://github.com/isaacs/ini/compare/v1.3.5...v1.3.8)
2021-06-11 Bump normalize-url in /Firmware/RaspberryPi/frontend-pi
    Bumps [normalize-url](https://github.com/sindresorhus/normalize-url) from 4.5.0 to 4.5.1.
    - [Release notes](https://github.com/sindresorhus/normalize-url/releases)
    - [Commits](https://github.com/sindresorhus/normalize-url/commits)
    ---
    updated-dependencies:
    - dependency-name: normalize-url
    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
2021-07-07 Bump glob-parent in /Firmware/RaspberryPi/frontend-pi
    Bumps [glob-parent](https://github.com/gulpjs/glob-parent) from 5.1.1 to 5.1.2.
    - [Release notes](https://github.com/gulpjs/glob-parent/releases)
    - [Changelog](https://github.com/gulpjs/glob-parent/blob/main/CHANGELOG.md)
    - [Commits](https://github.com/gulpjs/glob-parent/compare/v5.1.1...v5.1.2)
    - dependency-name: glob-parent
    dependency-type: indirect
    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
2022-12-07 Bump qs and express in /Firmware/RaspberryPi/frontend-pi
    Bumps [qs](https://github.com/ljharb/qs) to 6.11.0 and updates ancestor dependency [express](https://github.com/expressjs/express). These dependencies need to be updated together.
    Updates `qs` from 6.7.0 to 6.11.0
    - [Release notes](https://github.com/ljharb/qs/releases)
    - [Changelog](https://github.com/ljharb/qs/blob/main/CHANGELOG.md)
    - [Commits](https://github.com/ljharb/qs/compare/v6.7.0...v6.11.0)
    Updates `express` from 4.17.1 to 4.18.2
    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
